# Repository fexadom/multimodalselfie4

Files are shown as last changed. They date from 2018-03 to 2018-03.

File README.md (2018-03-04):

# MultimodalSelfie v4
The MultimodalSelfie is a personal multimodal recording device designed for traditional classrooms. The device, owned and operated by the student, sits on top of her desk while recording video, audio, and notes during a class session (as seen in the concept image below); effectively taking a "selfie" of her learning experience.

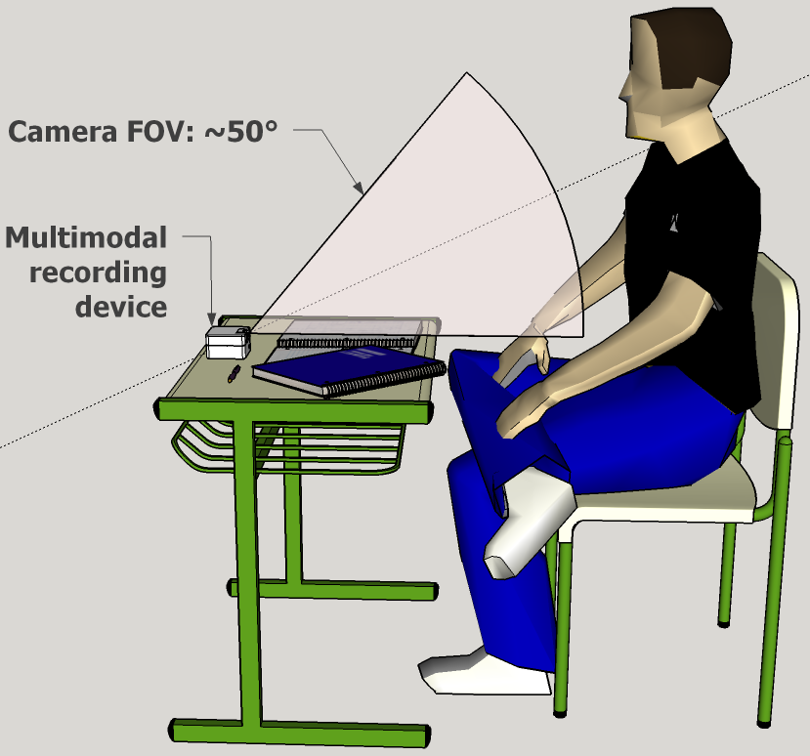
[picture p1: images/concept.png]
Concept use of MultimodalSelfie


## Design
This repository contains all the necessary information to construct and test the fourth version of the MultimodalSelfie device (MMSv4 for short). The MMSv4 is based on the [Raspberry Pi Zero W](https://www.raspberrypi.org/products/raspberry-pi-zero-w/) a stripped down version of the Raspberry Pi with wireless connectivity.

Front View | Components | Functionality
--- | --- | ---
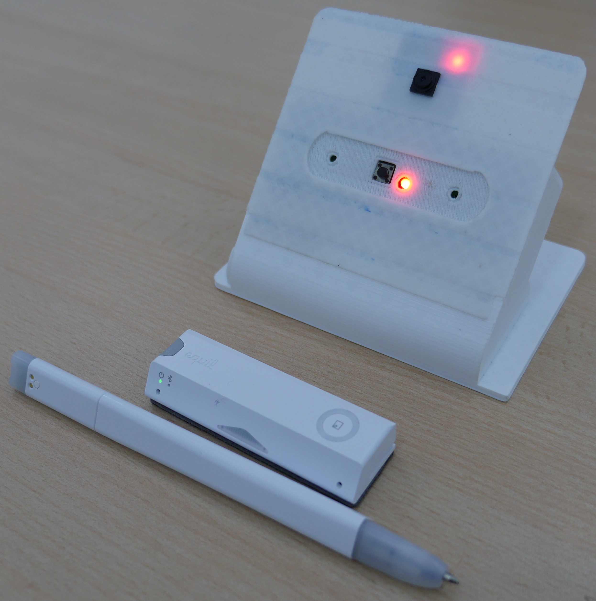
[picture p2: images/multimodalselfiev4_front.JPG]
MMSv4 Front
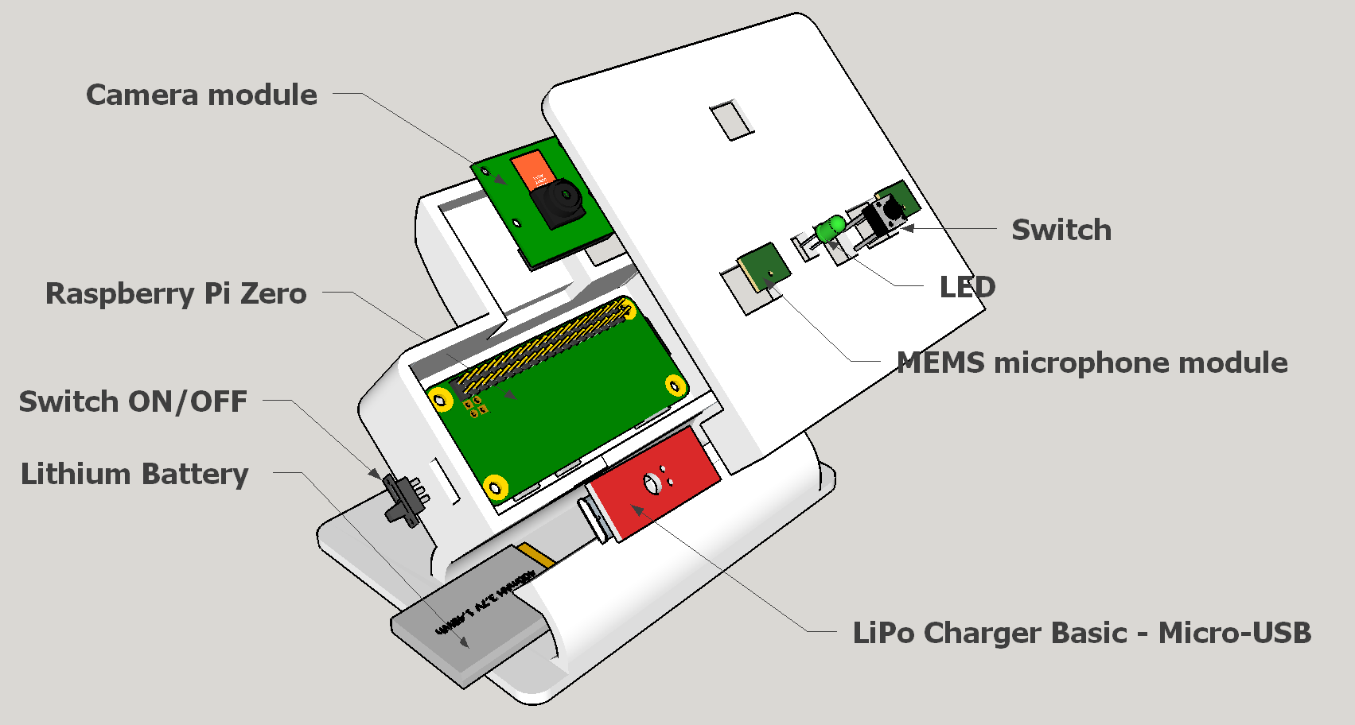
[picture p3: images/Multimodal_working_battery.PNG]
MMSv4 Components
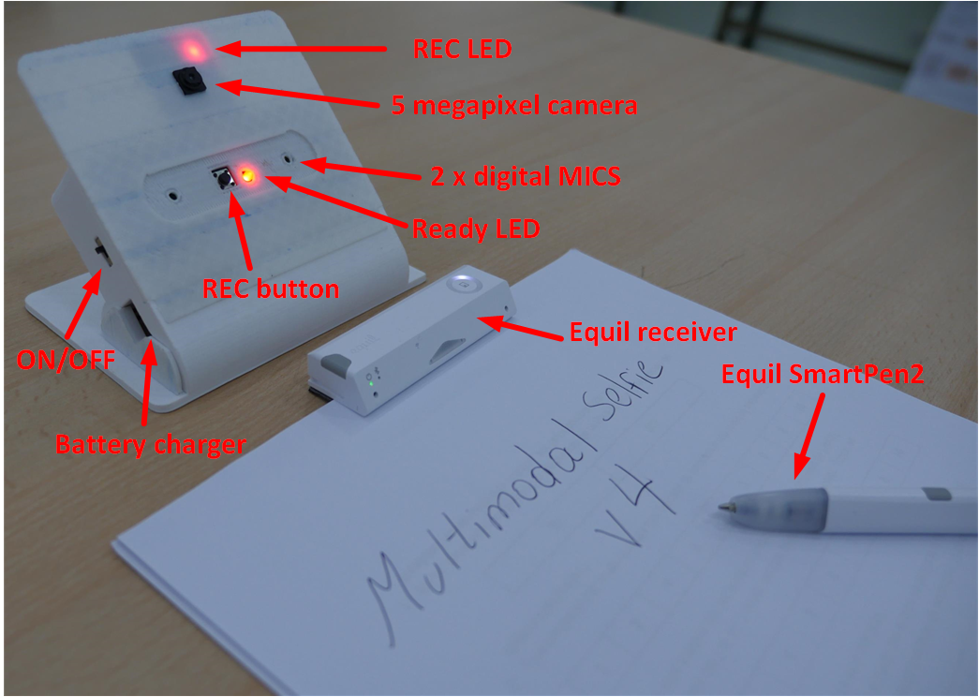
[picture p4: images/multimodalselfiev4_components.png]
MMSv4 Functionality
 |  | 

### Hardware components
The MMSv4 was built using the following components:

Component | Description | Notes
--- | --- | ---
Raspberry Pi Zero W | 1GHz 64-bit, single-core ARMv8 CPU, 512 MB RAM | 32 GB micro SD
Raspberry Pi Camera | Camera Rev 1.3, 5 megapixeles | Capable of 1080p HD video recording at 30fps
Smart Pen | Equil SmartPen2 | [Manufacturer website](https://www.myequil.com/smartpen2/)
3D Printed Case | Three parts printed using PLA | [STLs](/case)
Pihat | Printed Circuit Board that expands the Raspberry Pi capabilities, it connects to the 40 GPIO port. It has a swith, a LED, and two digital microphones. | [Design files](/pihat)
2 x digital MEMS microphones | The two ICS43432 mics are surface mounted on the Pihat and capable of stereo recording. | [Manufacturer website](https://www.invensense.com/products/digital/ics-43432/)
LiPo battery charger  | SparkFun LiPo Charger Basic - Micro-USB | [Manufacturer website](https://www.sparkfun.com/products/10217)
LiPo battery  | 2000mAh Lithium Ion battery | [Manufacturer website](https://www.sparkfun.com/products/13855)

### Software components
The operating system used is [Raspbian Stretch Lite](https://www.raspberrypi.org/downloads/raspbian/) (Release date 2017-11-29). Video and audio are captured and synchronized using **ffmpeg** and overall synchronization is done with Node-Red:
* [Node-Red flows](/synchronization-software)

## Dependencies
After installing Raspbian Stretch Lite (avoid installing any GUI and unnecessary packages) update as needed with:
```bash
sudo apt-get update
sudo apt-get upgrade
```
then install the following dependencies:

### ffmpeg
For best results, install ffmpeg and its dependencies from the official repository:
```bash
sudo apt-get install ffmpeg
```

### Node-RED
Node-RED is pre-installed in Raspbian Stretch, to enable it:
```bash
sudo systemctl enable nodered.service
```

### Equil
The Equil driver for the SmartPen2 requires Java, to install:
```bash
sudo apt-get install jsvc
```
## Configuration Notes
To use the camera port it is necessary to enable it at boot time, run:
```bash
sudo raspi-config
```
and enable the camera. To map the camera driver to /dev/video0 add this line to /etc/rc.local:
```bash
modprobe bcm2835-v4l2
```
### Installation of synchronization software
Install the contents of the [synchronization software](/synchronization-software) in the folder /opt/recording:
```bash
git clone https://github.com/fexadom/multimodalselfie4.git
cd multimodalselfie4
sudo mv synchronization-software /opt/recording
```
* Copy /opt/recording/node-red/settings.js to ~/.node-red/
* Copy the directory /opt/recording/node-red/node_modules/file-exists to ~/.node-red/node_modules/
* Create a directory "data" in /opt/recording
* Restart the system

### Configure Equil software
Open Equil.sh in /opt/recording/scripts/ and modify as needed:
```bash
JAVA_HOME: Location JAVA JRE
EXEC: Location JSVC
```
### Installation of ICS43432 driver
Use this post: [Add an I2S mic using device tree & simple-audio-card](https://www.raspberrypi.org/forums/viewtopic.php?f=44&t=173640) to install the driver for the ICS43432 digital microphones.

### Configure web server Lighttpd
The web server [Lighttpd](https://www.lighttpd.net/) is necessary to extract all recorded software. To install first remove Apache httpd if installed, then install **lighthttpd** from the official repositoty and enable the service:
```bash
sudo apt-get remove apache2
sudo apt-get install lighttpd
sudo systemctl enable lighttpd.service
```

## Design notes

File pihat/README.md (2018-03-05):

# Design files for pihat MultimodalSelfie version 4
The pihat for the MMSv4 is a two-layer PCB that connects to the 40-pin GPIO interface of the Raspberry Pi Zero W. It provides the following functionality to the MMSv4:
* Ready LED on GPIO 02
* Push button on GPIO 03
* Two digital MEMS ICS43432 microphones multiplexed together and connected to I2S interface of the Raspberry Pi (GPIO 18-20)

The design files in this repository were made in Eagle v8.

Pihat on device | Pihat front | Pihat back
--- | --- | ---
 |  |

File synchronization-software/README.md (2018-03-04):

# Multimodal Selfie capture synchronization
Automatic recording of audio, video, and pen strokes.

Created for Raspberry Pi Zero W, this setup records:
* Video and audio using ffmpeg
* Pen strokes using a Equil SmartPen2

It synchronizes recording by:
* Mqtt
  * START: topic >start
  * STOP: topic >stop
* Http
  * START: http://<IP ADDRESS DEVICE>:1880/start
  * STOP: http://<IP ADDRESS DEVICE>:1880/stop
* GPIO push button on Pin 05 (GPIO 03):
  * Press once >> START, press again >> STOP
* GPIO LED feedback on Pin 03 (GPIO 02):
  * LED ON: Ready to record, LED OFF: Not ready
* Record LED on camera:
  * LED ON: Recording, LED OFF: Not Recording

It uses the following scripts:
* scripts/do_ffmpeg.sh: starts recording video and audio with ffmpeg. It uses a 800x600 video resolution.
* scripts/controller.sh: starts/stops the smart pen recording.

This project should be installed in the following directory on the device:
* /opt/recording

## Data
When recording it produces in the data directory a folder[timestamp] with de following files:
* notas[int].txt: xy data from the smart pen
* output.mkv: video/audio file from ffmpeg

## Logs
Logs are maintened in the logs directory:
* node-red.log: Registers start/stop events and watchdog restart events
* ffmpeg.log: stderr output of the ffmpeg process
* Equil.err: Register start/stop events of the jsvc
* Equil.out: Register outputs events of the jsvc

## Node-red
Node-red code is in the node-red directory:
* flows_raspberrypi3.json: node-red flows
* settings.js: expected settings file. Copy this file to the local node-red installation folder.
* node-modules: this directory contains all node-red and node.js dependencies.

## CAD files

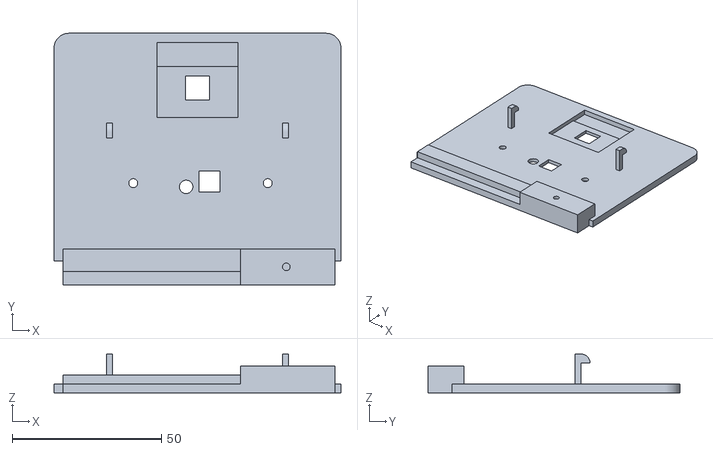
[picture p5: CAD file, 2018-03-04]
case/MULTIMODALZERO_V9_COVER.stl
96.0 x 84.1 x 13.0

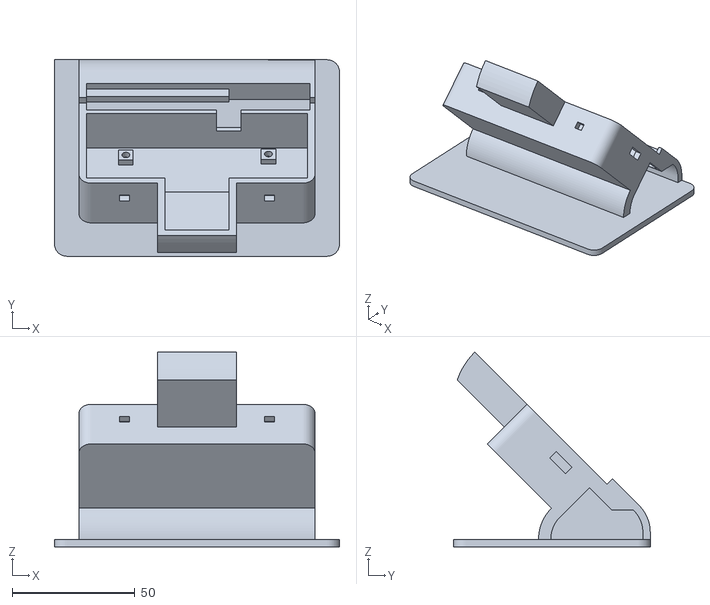
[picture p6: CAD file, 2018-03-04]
case/MULTIMODALZERO_V9_BOTTOM.stl
116.0 x 80.0 x 79.2

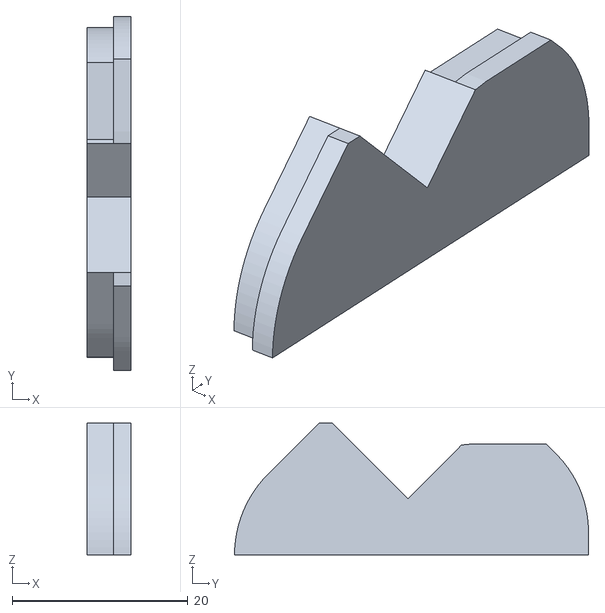
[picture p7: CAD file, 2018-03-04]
case/MULTIMODALZERO_V9_CLOSER.stl
5.00 x 40.2 x 15.0

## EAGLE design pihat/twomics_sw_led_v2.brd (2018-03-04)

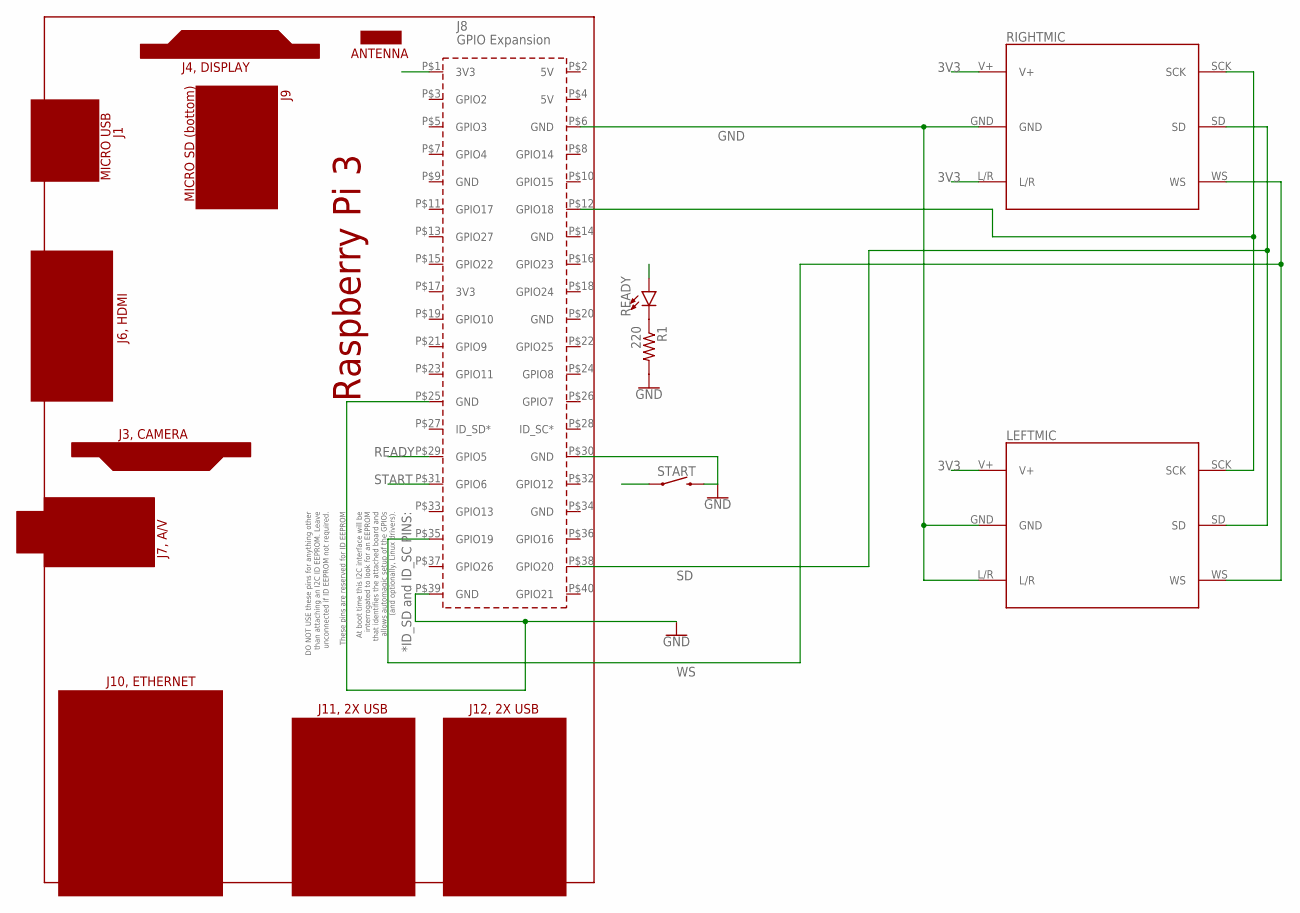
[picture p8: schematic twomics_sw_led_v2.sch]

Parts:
LEFTMIC: EMMIC-ICS43432; PTH
PCB1: RPI3_40_PIN; 40_PIN
R1: 220; 0207/7
READY: LED3MM; LED_3MM
RIGHTMIC: EMMIC-ICS43432; PTH
START: MOMENTARY-SWITCH-SPST-PTH-6.0MM; TACTILE_SWITCH_PTH_6.0MM

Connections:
3V3: LEFTMIC.V+, PCB1.P$1 (3V3), RIGHTMIC.L/R, RIGHTMIC.V+
GND: LEFTMIC.GND, LEFTMIC.L/R, PCB1.P$6 (GND), PCB1.P$25 (GND), PCB1.P$30 (GND), PCB1.P$39 (GND), R1.2, RIGHTMIC.GND, START.3 (2)
unnamed: R1.1, READY.K (C)
READY: PCB1.P$29 (GPIO5), READY.A
SCK: LEFTMIC.SCK, PCB1.P$12 (GPIO18), RIGHTMIC.SCK
SD: LEFTMIC.SD, PCB1.P$38 (GPIO20), RIGHTMIC.SD
START: PCB1.P$31 (GPIO6), START.1
WS: LEFTMIC.WS, PCB1.P$35 (GPIO19), RIGHTMIC.WS

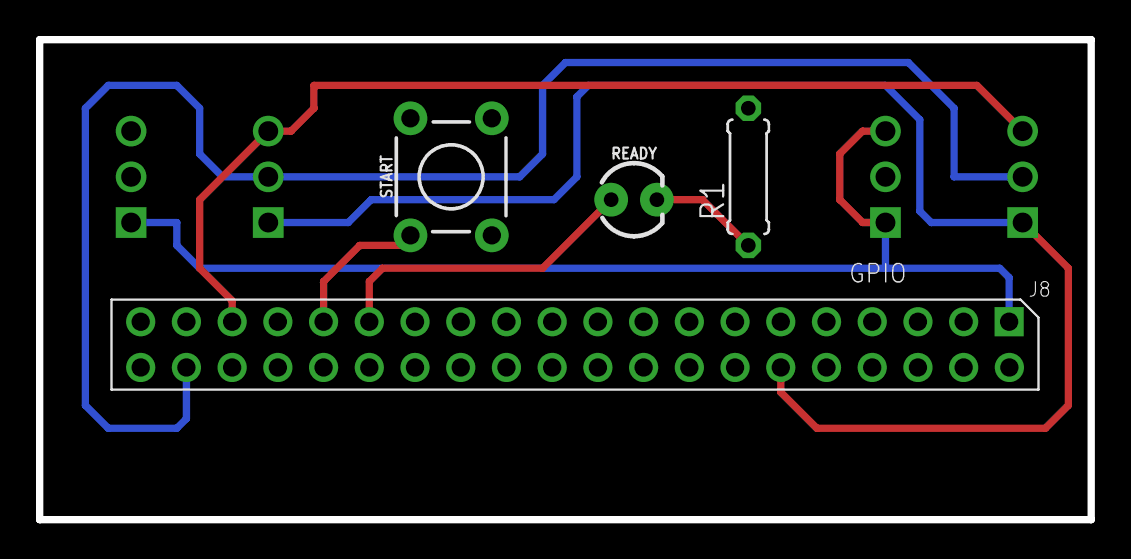
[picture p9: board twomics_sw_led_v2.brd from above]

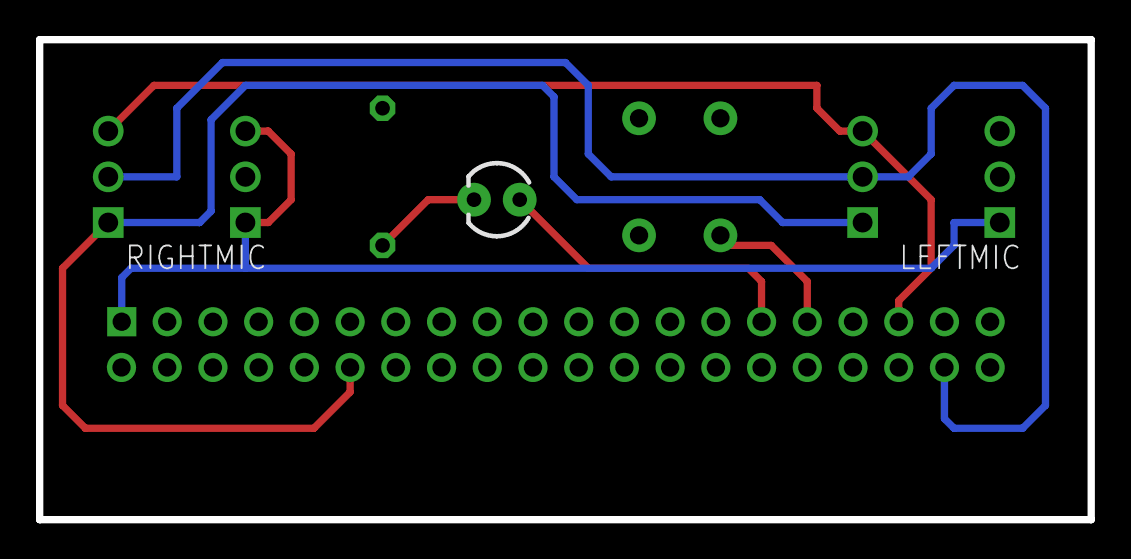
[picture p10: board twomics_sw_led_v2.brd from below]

Board: 2 copper layers, 58.4 x 26.7 mm, 6 parts (2 on the bottom side), 8 nets.

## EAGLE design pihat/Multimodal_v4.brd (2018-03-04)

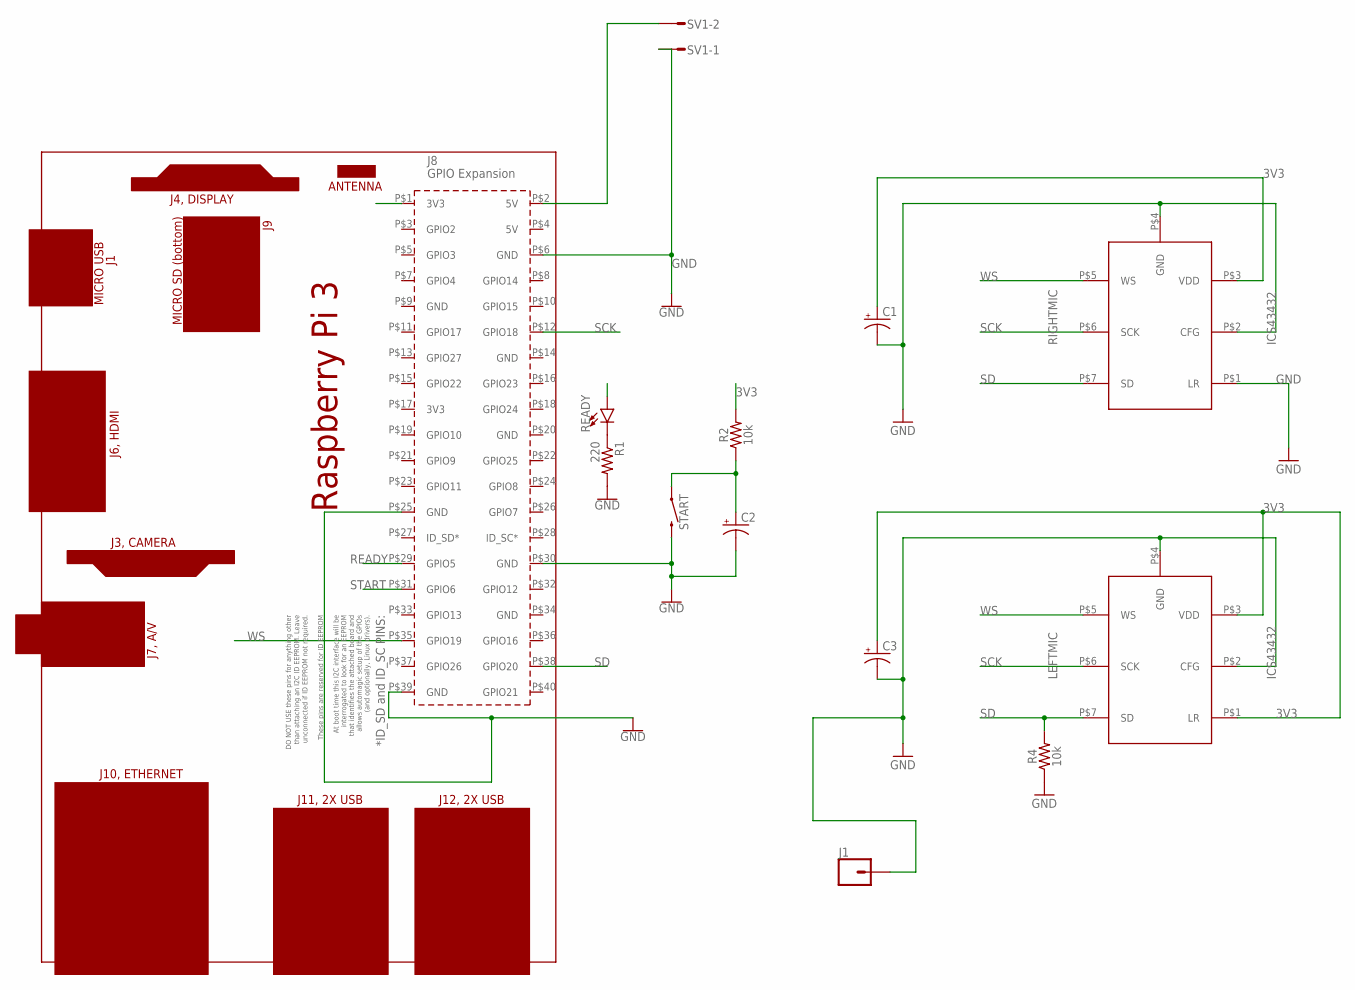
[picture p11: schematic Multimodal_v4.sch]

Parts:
C1, C2, C3: CPOL-USE2.5-5; E2,5-5
J1: CONN_01; 1X01
LEFTMIC: ICS43432
PCB1: RPI3_40_PIN; 40_PIN
R1: 220; 0207/7
R2, R4: 10k; AXIAL-0.3-KIT
READY: LED3MM; LED_3MM
RIGHTMIC: ICS43432
START: MOMENTARY-SWITCH-SPST-PTH-6.0MM; TACTILE_SWITCH_PTH_6.0MM
SV1: L02P

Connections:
3V3: C1.+, C3.+, LEFTMIC.P$1 (LR), LEFTMIC.P$3 (VDD), PCB1.P$1 (3V3), R2.P$2 (2), RIGHTMIC.P$3 (VDD)
GND: C1.-, C2.-, C3.-, J1.1, LEFTMIC.P$2 (CFG), LEFTMIC.P$4 (GND), PCB1.P$6 (GND), PCB1.P$25 (GND), PCB1.P$30 (GND), PCB1.P$39 (GND), R1.2, R4.P$1 (1), RIGHTMIC.P$1 (LR), RIGHTMIC.P$2 (CFG), RIGHTMIC.P$4 (GND), START.3 (2), SV1.1
unnamed: R1.1, READY.K (C)
unnamed: PCB1.P$2 (5V), SV1.2
READY: PCB1.P$29 (GPIO5), READY.A
SCK: LEFTMIC.P$6 (SCK), PCB1.P$12 (GPIO18), RIGHTMIC.P$6 (SCK)
SD: LEFTMIC.P$7 (SD), PCB1.P$38 (GPIO20), R4.P$2 (2), RIGHTMIC.P$7 (SD)
START: C2.+, PCB1.P$31 (GPIO6), R2.P$1 (1), START.1
WS: LEFTMIC.P$5 (WS), PCB1.P$35 (GPIO19), RIGHTMIC.P$5 (WS)

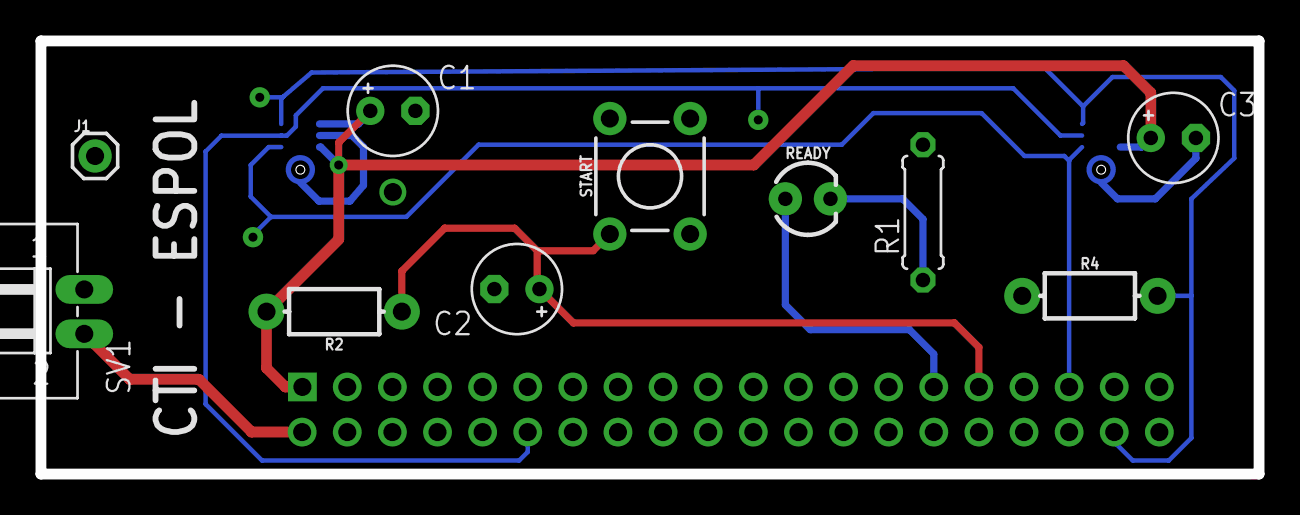
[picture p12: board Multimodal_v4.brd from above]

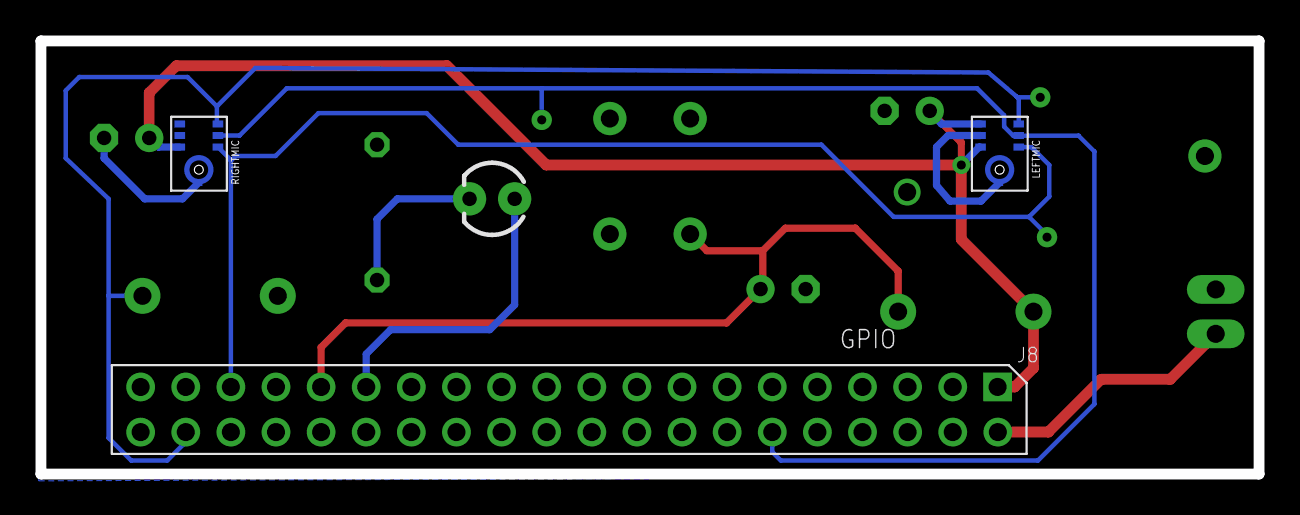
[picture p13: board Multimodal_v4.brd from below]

Board: 2 copper layers, 68.6 x 24.4 mm, 13 parts (3 on the bottom side), 9 nets.

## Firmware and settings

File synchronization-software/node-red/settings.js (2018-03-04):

/**
 * Copyright 2013, 2015 IBM Corp.
 *
 * Licensed under the Apache License, Version 2.0 (the "License");
 * you may not use this file except in compliance with the License.
 * You may obtain a copy of the License at
 *
 * http://www.apache.org/licenses/LICENSE-2.0
 *
 * Unless required by applicable law or agreed to in writing, software
 * distributed under the License is distributed on an "AS IS" BASIS,
 * WITHOUT WARRANTIES OR CONDITIONS OF ANY KIND, either express or implied.
 * See the License for the specific language governing permissions and
 * limitations under the License.
 **/

// The `https` setting requires the `fs` module. Uncomment the following
// to make it available:
//var fs = require("fs");

module.exports = {
    // the tcp port that the Node-RED web server is listening on
    uiPort: 1880,

    editorTheme: { menu: { "menu-item-help": {
        label: "Node-RED Pi Website",
        url: "http://nodered.org/docs/hardware/raspberrypi.html"
    } } },


    // By default, the Node-RED UI accepts connections on all IPv4 interfaces.
    // The following property can be used to listen on a specific interface. For
    // example, the following would only allow connections from the local machine.
    //uiHost: "127.0.0.1",

    // Retry time in milliseconds for MQTT connections
    mqttReconnectTime: 15000,

    // Retry time in milliseconds for Serial port connections
    serialReconnectTime: 15000,

    // Retry time in milliseconds for TCP socket connections
    //socketReconnectTime: 10000,

    // Timeout in milliseconds for TCP server socket connections
    //  defaults to no timeout
    //socketTimeout: 120000,

    // Timeout in milliseconds for HTTP request connections
    //  defaults to 120 seconds
    //httpRequestTimeout: 120000,

    // The maximum length, in characters, of any message sent to the debug sidebar tab
    debugMaxLength: 1000,

    // The file containing the flows. If not set, it defaults to flows_<hostname>.json
    flowFile: 'flows_multimodalselfie.json',

    // To enabled pretty-printing of the flow within the flow file, set the following
    //  property to true:
    flowFilePretty: true,

    // By default, all user data is stored in the Node-RED install directory. To
    // use a different location, the following property can be used
    userDir: '/opt/recording/node-red/',

    // Node-RED scans the `nodes` directory in the install directory to find nodes.
    // The following property can be used to specify an additional directory to scan.
    nodesDir: '/opt/recording/node-red/nodes',

    // By default, the Node-RED UI is available at http://localhost:1880/
    // The following property can be used to specifiy a different root path.
    // If set to false, this is disabled.
    //httpAdminRoot: '/admin',

    // Some nodes, such as HTTP In, can be used to listen for incoming http requests.
    // By default, these are served relative to '/'. The following property
    // can be used to specifiy a different root path. If set to false, this is
    // disabled.
    //httpNodeRoot: '/red-nodes',

    // The following property can be used in place of 'httpAdminRoot' and 'httpNodeRoot',
    // to apply the same root to both parts.
    //httpRoot: '/red',

    // When httpAdminRoot is used to move the UI to a different root path, the
    // following property can be used to identify a directory of static content
    // that should be served at http://localhost:1880/.
    //httpStatic: '/home/nol/node-red-dashboard/',

    // Securing Node-RED
    // -----------------
    // To password protect the Node-RED editor and admin API, the following
    // property can be used. See http://nodered.org/docs/security.html for details.
    //adminAuth: {
    //    type: "credentials",
    //    users: [{
    //        username: "admin",
    //        password: "$2a$08$zZWtXTja0fB1pzD4sHCMyOCMYz2Z6dNbM6tl8sJogENOMcxWV9DN.",
    //        permissions: "*"
    //    }]
    //},

    // To password protect the node-defined HTTP endpoints (httpNodeRoot), or
    // the static content (httpStatic), the following properties can be used.
    // The pass field is a bcrypt hash of the password.
    // See http://nodered.org/docs/security.html#generating-the-password-hash
    //httpNodeAuth: {user:"user",pass:"$2a$08$zZWtXTja0fB1pzD4sHCMyOCMYz2Z6dNbM6tl8sJogENOMcxWV9DN."},
    //httpStaticAuth: {user:"user",pass:"$2a$08$zZWtXTja0fB1pzD4sHCMyOCMYz2Z6dNbM6tl8sJogENOMcxWV9DN."},

    // The following property can be used to enable HTTPS
    // See http://nodejs.org/api/https.html#https_https_createserver_options_requestlistener
    // for details on its contents.
    // See the comment at the top of this file on how to load the `fs` module used by
    // this setting.
    //
    //https: {
    //    key: fs.readFileSync('privatekey.pem'),
    //    cert: fs.readFileSync('certificate.pem')
    //},

    // The following property can be used to disable the editor. The admin API
    // is not affected by this option. To disable both the editor and the admin
    // API, use either the httpRoot or httpAdminRoot properties
    //disableEditor: false,

    // The following property can be used to configure cross-origin resource sharing
    // in the HTTP nodes.
    // See https://github.com/troygoode/node-cors#configuration-options for
    // details on its contents. The following is a basic permissive set of options:
    //httpNodeCors: {
    //    origin: "*",
    //    methods: "GET,PUT,POST,DELETE"
    //},

    // If you need to set an http proxy please set an environment variable
    // called http_proxy (or HTTP_PROXY) outside of Node-RED in the operating system.
    // For example - http_proxy=http://myproxy.com:8080
    // (Setting it here will have no effect)
    // You may also specify no_proxy (or NO_PROXY) to supply a comma separated
    // list of domains to not proxy, eg - no_proxy=.acme.co,.acme.co.uk

    // The following property can be used to add a custom middleware function
    // in front of all http in nodes. This allows custom authentication to be
    // applied to all http in nodes, or any other sort of common request processing.
    //httpNodeMiddleware: function(req,res,next) {
    //   // Handle/reject the request, or pass it on to the http in node
    //   // by calling next();
    //   next();
    //},

    // Anything in this hash is globally available to all functions.
    // It is accessed as context.global.
    // eg:
    //    functionGlobalContext: { os:require('os') }
    // can be accessed in a function block as:
    //    context.global.os

    functionGlobalContext: {
        // os:require('os'),
        // octalbonescript:require('octalbonescript'),
        // jfive:require("johnny-five"),
        // j5board:require("johnny-five").Board({repl:false})
	fileExists:require('file-exists')
    },
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

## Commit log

2018-03-04 Upload software and hardware files
    [Multimodal_v4.brd, Multimodal_v4.sch, twomics_sw_led.brd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]
2018-03-04 Adding case files
    [MULTIMODALZERO_V9_BOTTOM.stl, MULTIMODALZERO_V9_CLOSER.stl, MULTIMODALZERO_V9_COVER.stl]

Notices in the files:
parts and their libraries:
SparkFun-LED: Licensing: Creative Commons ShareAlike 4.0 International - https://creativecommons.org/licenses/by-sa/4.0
